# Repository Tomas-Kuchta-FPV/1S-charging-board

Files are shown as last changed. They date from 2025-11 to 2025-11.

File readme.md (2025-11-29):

# 1S charging board
> A compact adapter board that lets standard RC chargers safely charge 1S batteries.

It allows you to charge up to six 1s batteries on a universal RC charger.  
Some chargers can display series resistance and capacity. So you know the conditions of the cells.  
Connectors like **BT2.0/A30** and **XT30** are suported. And with an adapter, you can charge **18650** batteries.  

## Photos
### Main PCB
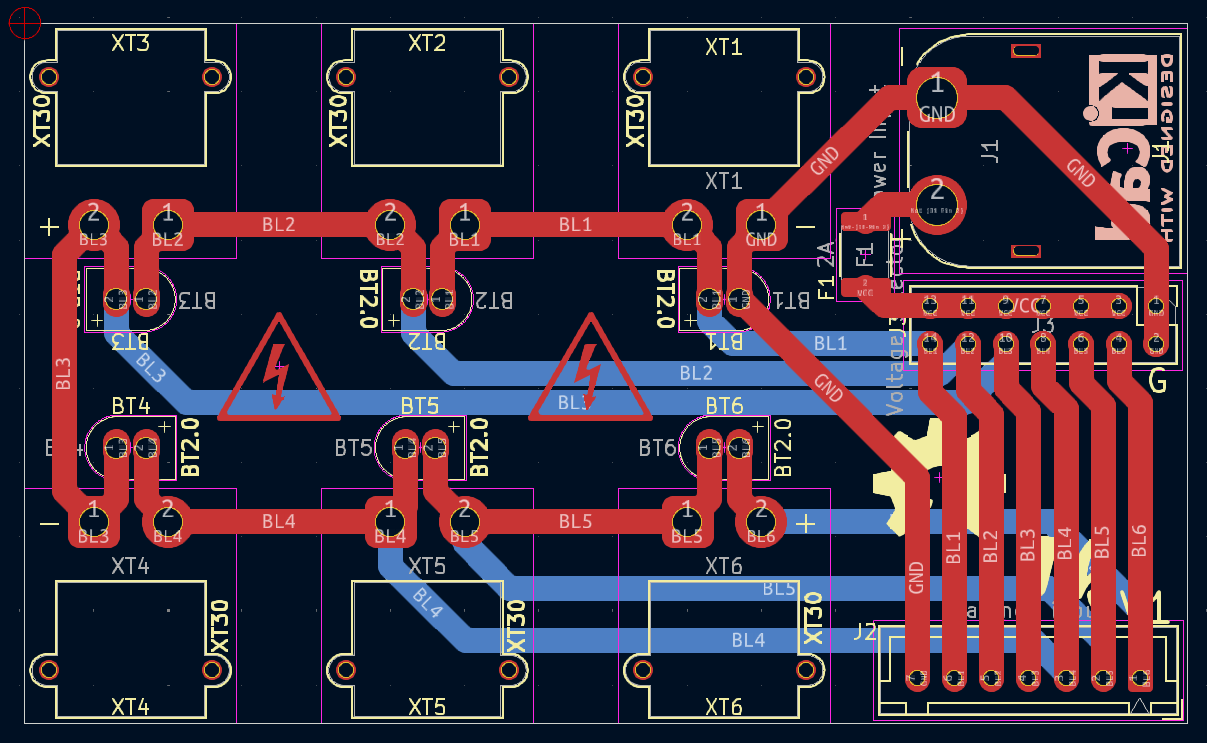
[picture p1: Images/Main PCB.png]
Main PCB

### XT30 to 18650
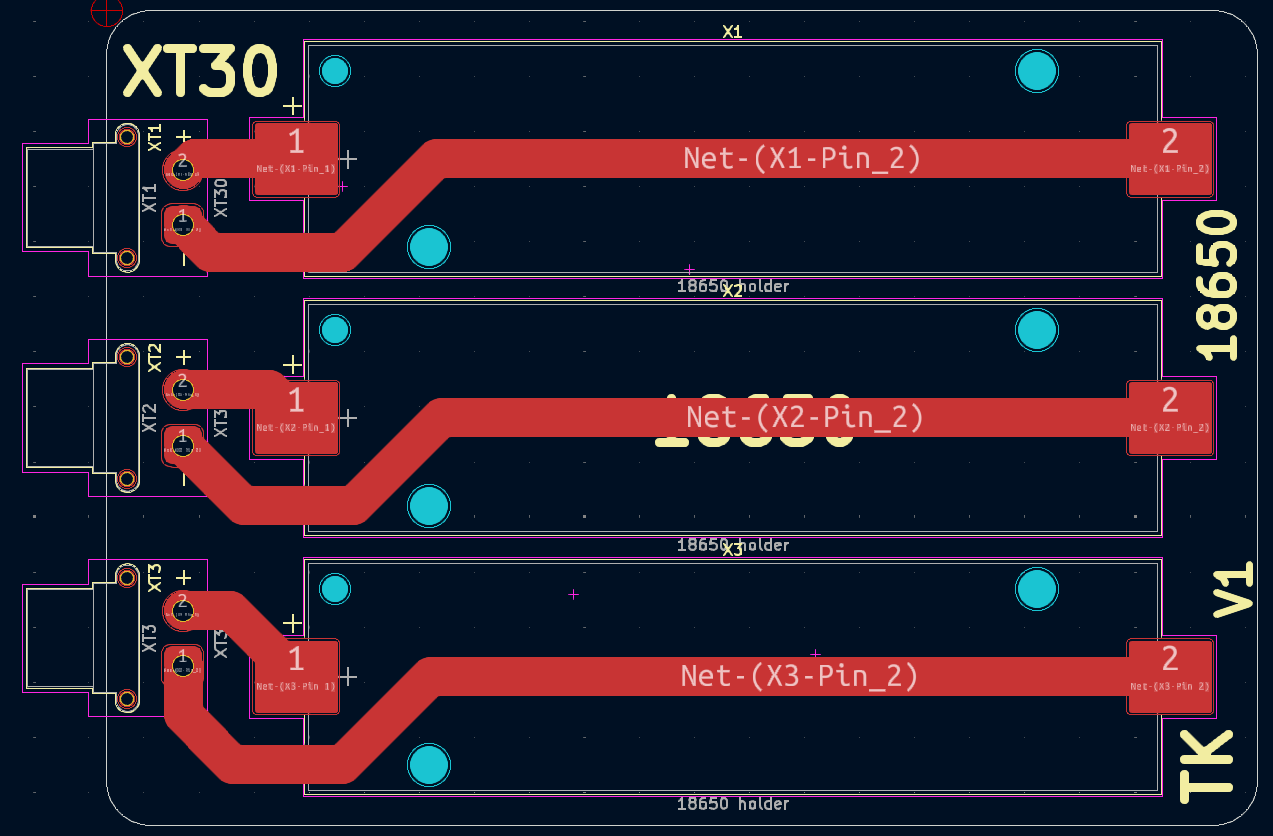
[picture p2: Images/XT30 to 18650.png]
XT30 to 18650


## Motivation
I have a great RC charger (ISDT D1), and it measures internal resistance and capacity, which is awesome!  
There are a lot of 18650 cells of unknown condition lying in my workshop. I would like to know if they are still good or if they belong in the trash.  
Also, I love RC hobby. So why not use a universal both RC charger for RC and maker stuff?  
That's why there is a main PCB with XT30 and BT 2.0 connectors. And an extension board for 18650.

### Design constraints
- It should work with these battery types and connctors:
    - Modular design with BT2.0 on top and XT30 on the sides for modules.
    - XT30 - Main board
    - BT2.0 / A30 Main board
    - PH2.0 - future adapters if I need them
    - 18650 batteries - XT30 to 18650
- easy to use
- A fuse - 2A Polyfuze
- 6S MAX

## BOM
| Item | Qty | Price | Link |
| :--- | :-- | :---- | :--- |
| | | | |
| BT2.0M | 6 | 7.15  | https://www.aliexpress.com/item/1005004465425088.html |
| 2A Polyfuse | 1 | 0.51  | https://www.lcsc.com/product-detail/C960026.html |
| XT60 - Power Input | 1 | 0.59  | https://www.lcsc.com/product-detail/C98732.html |
| 1x7P -  Balance input | 1 | 0.54  | https://www.lcsc.com/product-detail/C144398.html |
| 2x07 PinHeader | 1 | 1.4 | https://www.lcsc.com/product-detail/C2897408.html |
| XT30M | 6 | 1.72  | https://www.lcsc.com/product-detail/C431092.html |
| | | | |
| XT30F | 6 | 1.92  | https://www.lcsc.com/product-detail/C2913282.html |
| 18650 holder | 6 | 7.52  | https://www.lcsc.com/product-detail/C2988620.html |
| LCSC Shipping | | 11.2  | |
| PCB fabrication + shipping | 2 | 21.9  | |
| | | 54.45 | |

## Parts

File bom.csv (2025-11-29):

Reference | Qty | Price $ | Value | Footprint | LCSC | Aliexpress
Main PCB
BT1,BT2,BT3,BT4,BT5,BT6 | 6 | 7.15 | BT2.0 | BT20:BT20 | - | https://www.aliexpress.com/item/1005004465425088.html
F1 | 1 | 0.51 | 2A | Fuse:Fuse_1812_4532Metric_Pad1.30x3.40mm_HandSolder | C960026
J1 | 1 | 0.59 | Power Input | Connector_AMASS:AMASS_XT60PW-M_1x02_P7.20mm_Horizontal | C98732
J2 | 1 | 0.54 | Balance input | Connector_JST:JST_XH_B7B-XH-A_1x07_P2.50mm_Vertical | C144398
J3 | 1 | 1.40 | Voltage selector | Connector_PinHeader_2.54mm:PinHeader_2x07_P2.54mm_Vertical | C2897408
XT1,XT2,XT3,XT4,XT5,XT6 | 6 | 1.72 | XT30 | Connector_AMASS:AMASS_XT30PW-M_1x02_P2.50mm_Horizontal | C431092
XT30 to 18650
XT1,XT2,XT3 | 6 | 1.92 | XT30 | Connector_AMASS:AMASS_XT30PW-F_1x02_P2.50mm_Horizontal | C2913282
X1,X2,X3 | 6 | 7.52 | 18650 holder | Battery:BatteryHolder_Keystone_1042_1x18650 | C2988620
LCSC Shipping |  | 11.20
PCB fabrication + shipping | 2 | 21.90
 |  | 54.45

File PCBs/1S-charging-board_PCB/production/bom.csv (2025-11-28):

Designator | Footprint | Quantity | Value | LCSC Part #
BT1, BT2, BT3, BT4, BT5, BT6 | BT20 | 6 | BT2.0 | -
F1 | 1812 | 1 | 2A | C960026
J1 | AMASS_XT60PW-M_1x02_P7.20mm_Horizontal | 1 | Power Input | C98732
J2 | JST_XH_B7B-XH-A_1x07_P2.50mm_Vertical | 1 | Balance input | C144398
J3 | PinHeader_2x07_P2.54mm_Vertical | 1 | Voltage selector | C2897408
XT1, XT2, XT3, XT4, XT5, XT6 | AMASS_XT30PW-M_1x02_P2.50mm_Horizontal | 6 | XT30 | C431092

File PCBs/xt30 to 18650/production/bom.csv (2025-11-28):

Designator | Footprint | Quantity | Value | LCSC Part #
BGA | BGA-152_14x18mm_Layout13x17_P1mm | 1 | BGA-152_14x18mm_Layout13x17_P1mm
PRETTY INDUCTOR FOOTPRINT | L_Sagami_CER1257B | 1 | L_Sagami_CER1257B
X1, X2, X3 | BatteryHolder_Keystone_1042_1x18650 | 3 | 18650 holder | C2988620
XT1, XT2, XT3 | AMASS_XT30PW-F_1x02_P2.50mm_Horizontal | 3 | XT30 | C2913282

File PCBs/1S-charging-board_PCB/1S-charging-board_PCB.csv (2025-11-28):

Reference | Qty | Value | Footprint | LCSC | Aliexpress
BT1,BT2,BT3,BT4,BT5,BT6 | 6 | BT2.0 | BT20:BT20 | - | https://www.aliexpress.com/item/1005004465425088.html
F1 | 1 | 2A | Fuse:Fuse_1812_4532Metric_Pad1.30x3.40mm_HandSolder | C960026
J1 | 1 | Power Input | Connector_AMASS:AMASS_XT60PW-M_1x02_P7.20mm_Horizontal | C98732
J2 | 1 | Balance input | Connector_JST:JST_XH_B7B-XH-A_1x07_P2.50mm_Vertical | C144398
J3 | 1 | Voltage selector | Connector_PinHeader_2.54mm:PinHeader_2x07_P2.54mm_Vertical | C2897408
XT1,XT2,XT3,XT4,XT5,XT6 | 6 | XT30 | Connector_AMASS:AMASS_XT30PW-M_1x02_P2.50mm_Horizontal | C431092

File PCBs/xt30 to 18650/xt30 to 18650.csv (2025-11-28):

Reference | Qty | Value | Footprint | LCSC
XT1,XT2,XT3 | 3 | XT30 | Connector_AMASS:AMASS_XT30PW-F_1x02_P2.50mm_Horizontal | C2913282
X1,X2,X3 | 3 | 18650 holder | Battery:BatteryHolder_Keystone_1042_1x18650 | C2988620

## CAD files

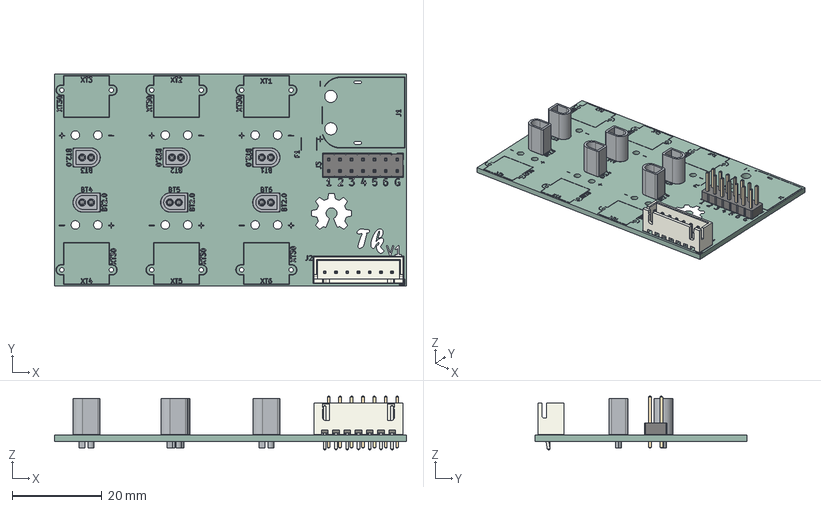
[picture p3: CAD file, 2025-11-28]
PCBs/1S-charging-board_PCB/1S-charging-board_PCB.step
78.3 x 47.2 x 11.9 mm
BT2.0-from_Riley x 6
PinHeader_2x07_P2.54mm_Vertical
JST_XH_B7B-XH-A_1x07_P2.50mm_Vertical
1S-charging-board_PCB_silkscreen x 2
1S-charging-board_PCB_PCB

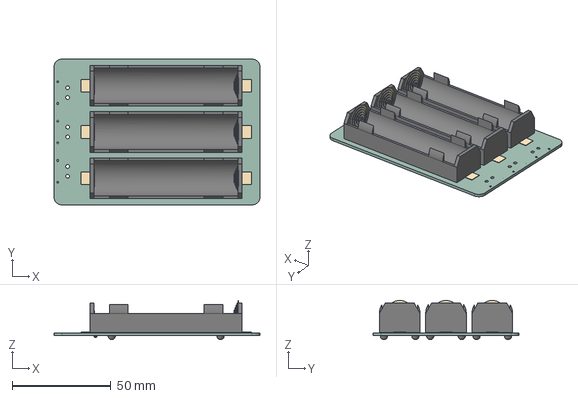
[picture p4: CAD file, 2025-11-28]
PCBs/xt30 to 18650/xt30 to 18650.step
104.5 x 74.0 x 19.8 mm
BatteryHolder_Keystone_1042_1x18650 x 3
xt30 to 18650_PCB

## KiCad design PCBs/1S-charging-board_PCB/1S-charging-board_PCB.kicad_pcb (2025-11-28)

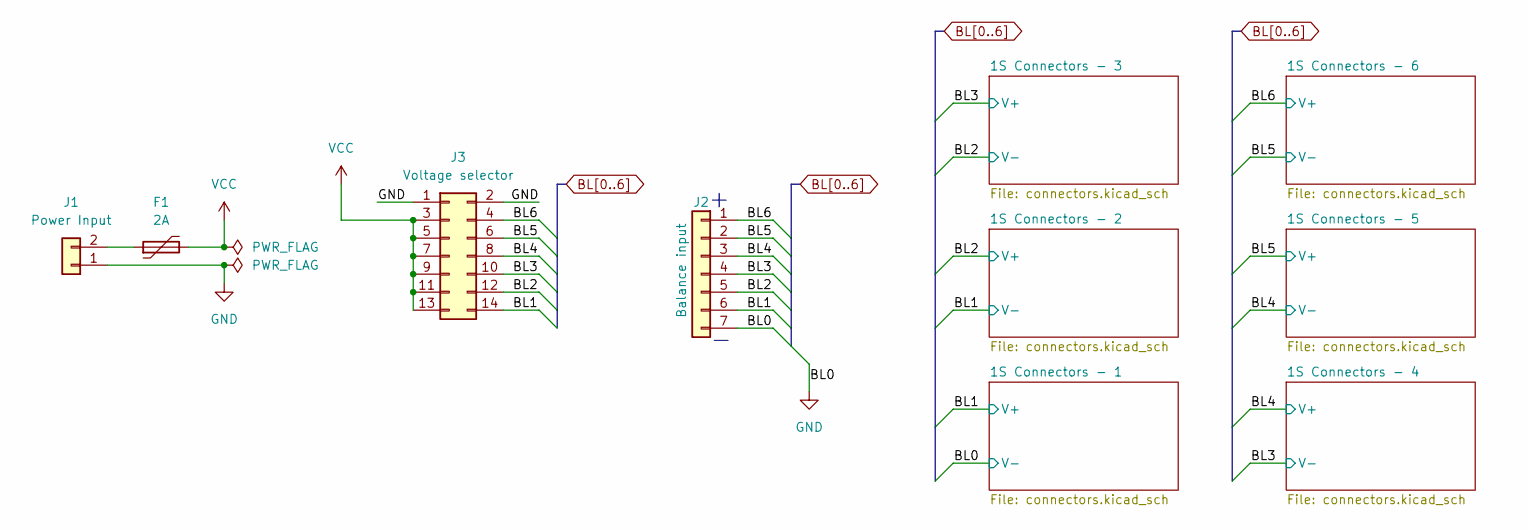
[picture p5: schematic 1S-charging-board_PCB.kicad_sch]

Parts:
F1: 2A; Fuse_1812_4532Metric_Pad1.30x3.40mm_HandSolder; LCSC C960026
J1: Power Input; AMASS_XT60PW-M_1x02_P7.20mm_Horizontal; LCSC C98732
J2: Balance input; JST_XH_B7B-XH-A_1x07_P2.50mm_Vertical; LCSC C144398
J3: Voltage selector; PinHeader_2x07_P2.54mm_Vertical; LCSC C2897408

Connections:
BL1: J2.6, J3.14; also elsewhere on the board
BL2: J2.5, J3.12; also elsewhere on the board
BL3: J2.4, J3.10; also elsewhere on the board
BL4: J2.3, J3.8; also elsewhere on the board
BL5: J2.2, J3.6; also elsewhere on the board
BL6: J2.1, J3.4; also elsewhere on the board
GND: J1.1, J2.7, J3.1, J3.2; also elsewhere on the board
unnamed: F1.1, J1.2
VCC: F1.2, J3.3, J3.5, J3.7, J3.9, J3.11, J3.13

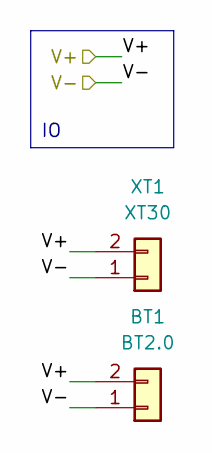
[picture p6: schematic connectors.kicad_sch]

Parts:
BT1: BT2.0; BT20
XT1: XT30; AMASS_XT30PW-M_1x02_P2.50mm_Horizontal; LCSC C431092

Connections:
BL1: BT1.2, XT1.2; also elsewhere on the board
GND: BT1.1, XT1.1; also elsewhere on the board

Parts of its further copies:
BT2, BT3, BT4, BT5, BT6: BT2.0; BT20
XT2, XT3, XT4, XT5, XT6: XT30; AMASS_XT30PW-M_1x02_P2.50mm_Horizontal; LCSC C431092

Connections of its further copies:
BL1: BT2.1, XT2.1; also elsewhere on the board
BL2: BT2.2, BT3.1, XT2.2, XT3.1; also elsewhere on the board
BL3: BT3.2, BT4.1, XT3.2, XT4.1; also elsewhere on the board
BL4: BT4.2, BT5.1, XT4.2, XT5.1; also elsewhere on the board
BL5: BT5.2, BT6.1, XT5.2, XT6.1; also elsewhere on the board
BL6: BT6.2, XT6.2; also elsewhere on the board

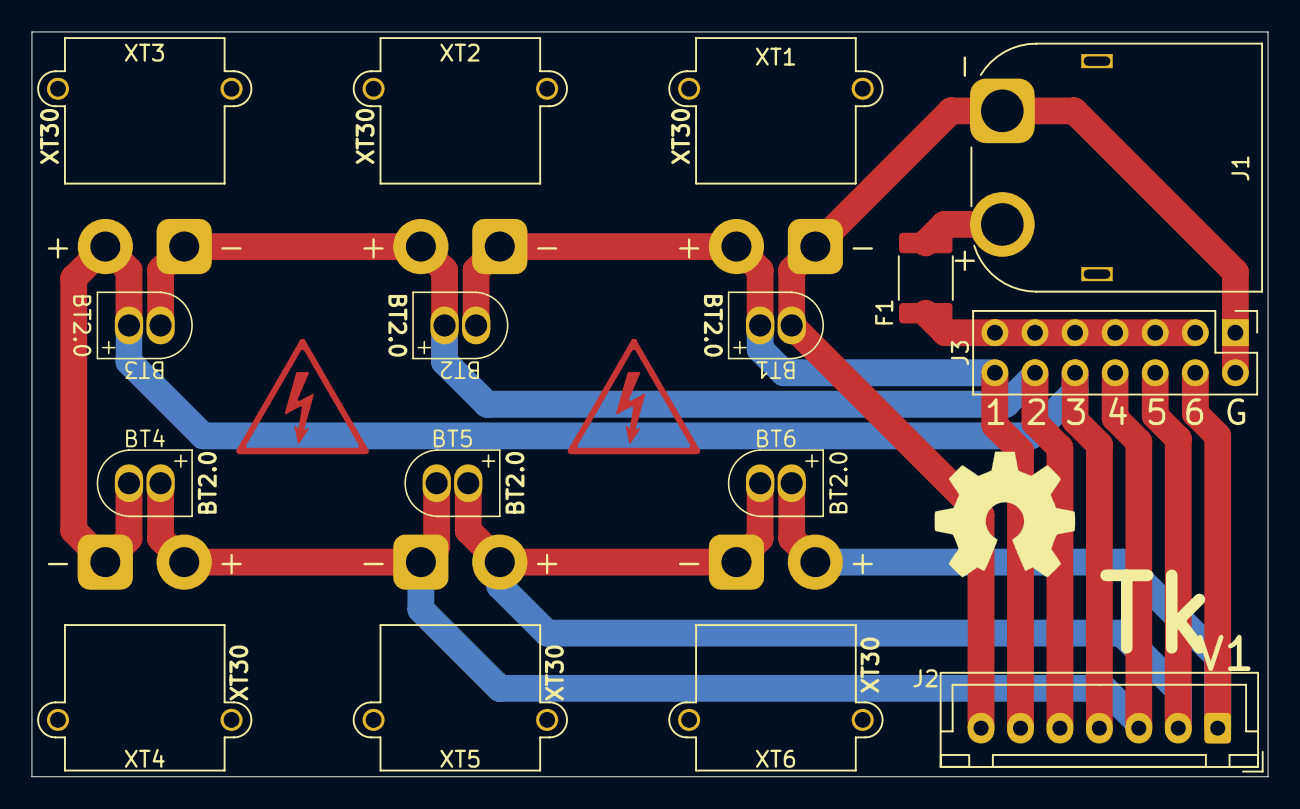
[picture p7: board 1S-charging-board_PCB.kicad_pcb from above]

Board: 2 copper layers, 78.3 x 47.2 mm, 16 parts (0 on the bottom side), 9 nets.

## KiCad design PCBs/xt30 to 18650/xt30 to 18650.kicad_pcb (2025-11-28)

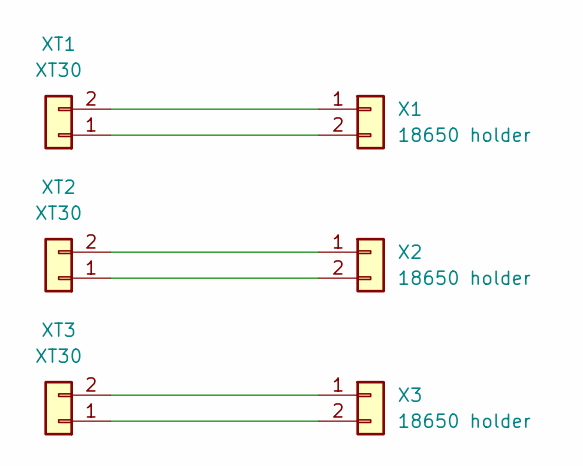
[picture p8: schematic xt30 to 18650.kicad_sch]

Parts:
X1, X2, X3: 18650 holder; BatteryHolder_Keystone_1042_1x18650; LCSC C2988620
XT1, XT2, XT3: XT30; AMASS_XT30PW-F_1x02_P2.50mm_Horizontal; LCSC C2913282

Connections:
unnamed: X1.1, XT1.2
unnamed: X1.2, XT1.1
unnamed: X2.1, XT2.2
unnamed: X2.2, XT2.1
unnamed: X3.1, XT3.2
unnamed: X3.2, XT3.1

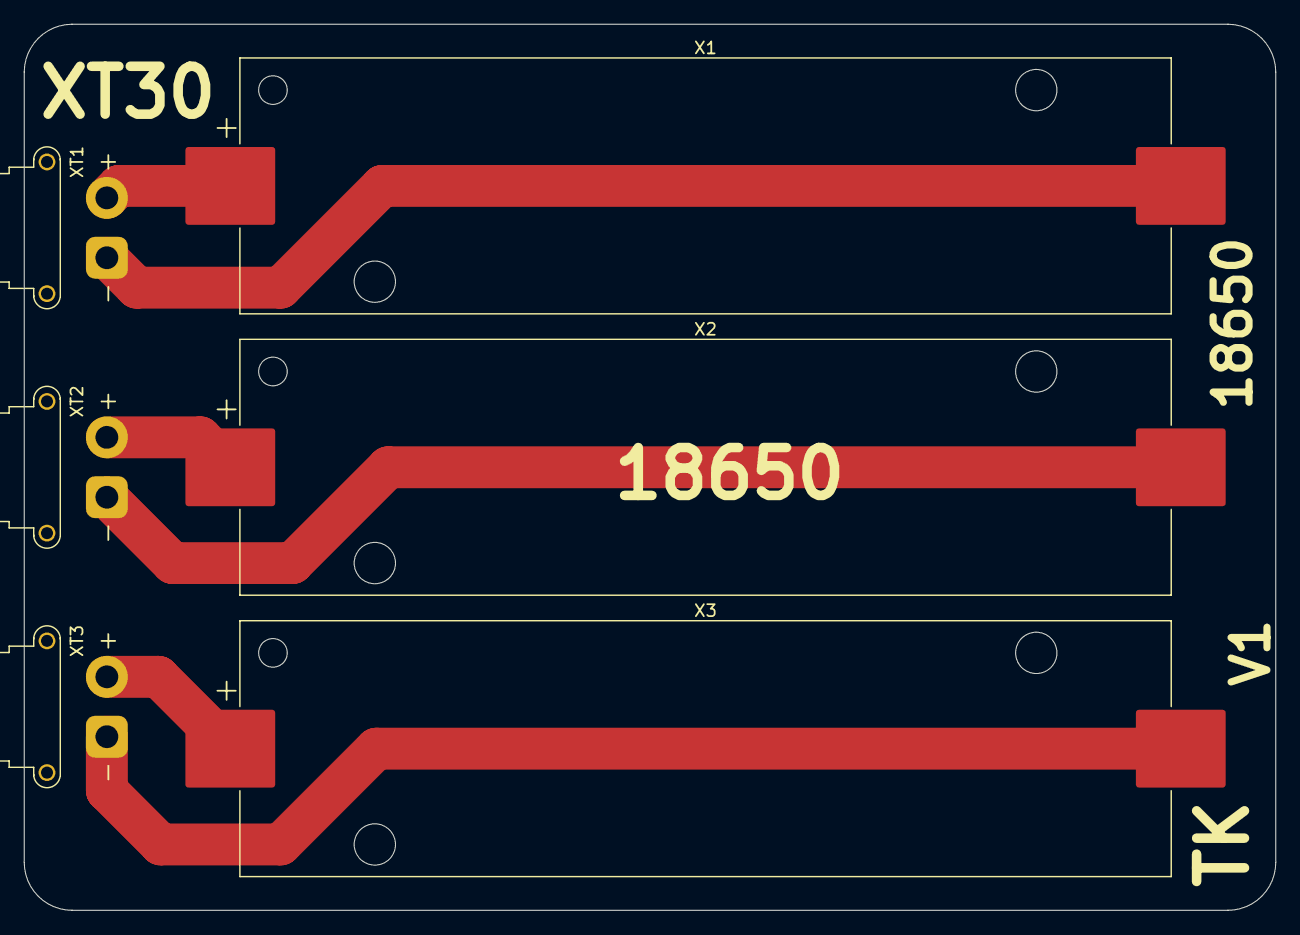
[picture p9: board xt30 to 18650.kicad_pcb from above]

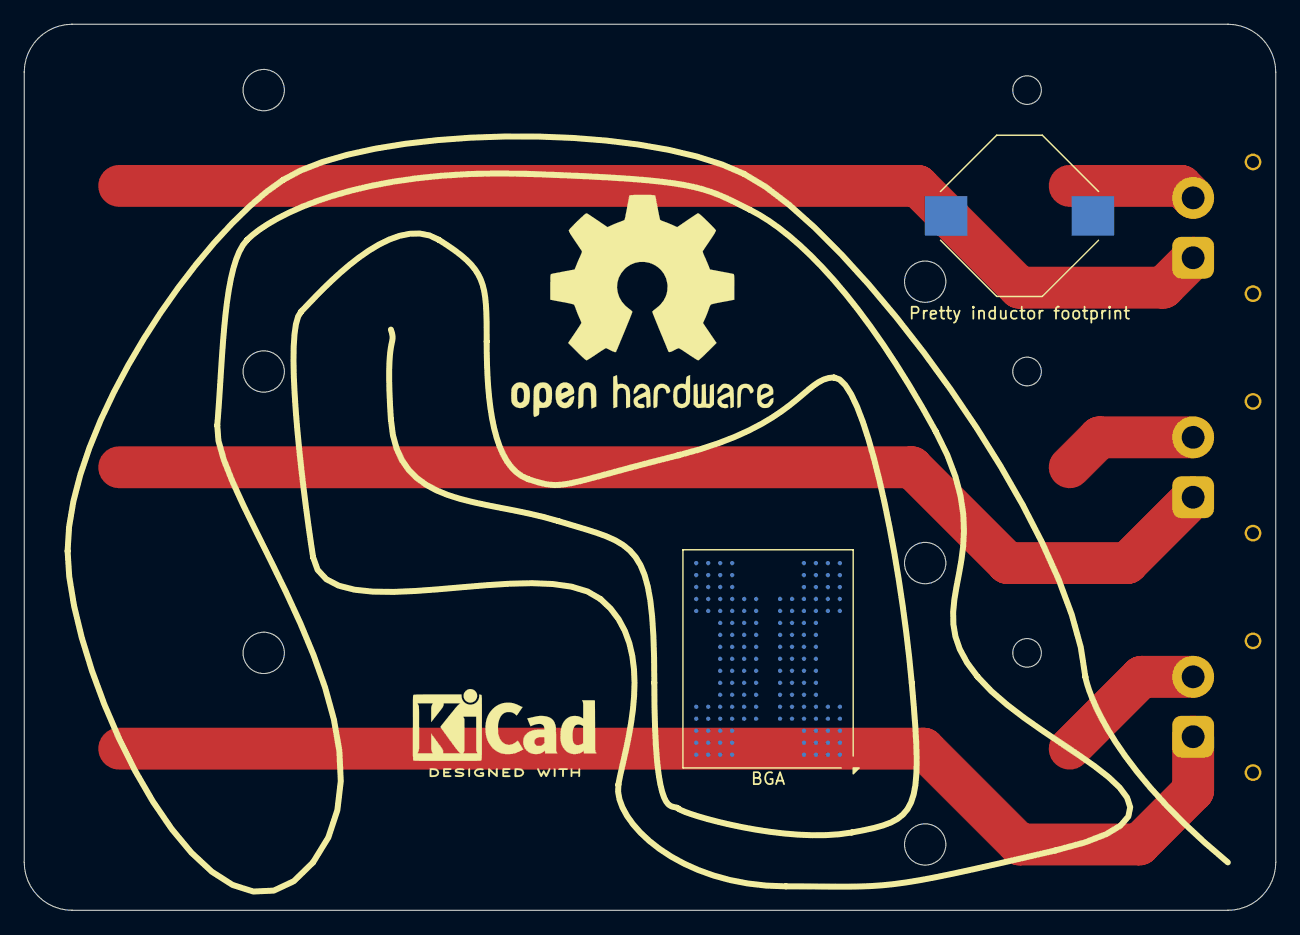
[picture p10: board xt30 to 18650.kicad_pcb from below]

Board: 2 copper layers, 104.5 x 74.0 mm, 8 parts (2 on the bottom side), 6 nets.

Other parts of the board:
BGA: BGA-152_14x18mm_Layout13x17_P1mm
Pretty inductor footprint: L_Sagami_CER1257B

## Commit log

2025-11-19 Added PCB with schematic pretty much finished
    [1S-charging-board_PCB.kicad_pcb, 1S-charging-board_PCB.kicad_sch, connectors.kicad_sch]
2025-11-25 Finished the 1s charging board.
    [1S-charging-board_PCB.kicad_pcb, 1S-charging-board_PCB.kicad_sch]
2025-11-28 Made a XT30 to 18650 board.
    [1S-charging-board_PCB.kicad_pcb, xt30 to 18650.kicad_pcb, xt30 to 18650.kicad_sch]
2025-11-28 prep for submiting
    [1S-charging-board_PCB.kicad_pcb, 1S-charging-board_PCB.kicad_sch, 1S-charging-board_PCB.step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]
2025-11-28 added BOM and other CSV stuff
    [1S-charging-board_PCB.csv, bom.csv, designators.csv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]
2025-11-29 Forgor shipping on aliexpress
    [bom.csv]
